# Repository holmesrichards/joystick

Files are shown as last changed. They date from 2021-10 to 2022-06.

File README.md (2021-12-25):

# Analog Output Joystick

This is a Kosmo format synth module that provides an interface for an analog joystick. The X and Y outputs provide control voltages that vary with the horizontal and vertical positions, respectively, of the joystick.

There are range control pots for X and Y. These adjust the width of the control voltage range. With the width fully clockwise the control voltage range is about 10 V end to end.

There also are offset control pots. These add a DC offset of between -5 V and 5 V to the output. So with the range pot at maximum and the offset pot centered the output voltage ranges from about -5 V to 5 V; with the offset pot fully clockwise the output voltage range is about 0 V to 10 V.

The X output voltage increases as you move the joystick from left to right, and Y increases from down to up. There also are two inverted output jacks; here the X output increases from right to left and the Y increases from up to down. Both outputs have the same range and same offset (with same sign), so for instance if the regular output is from 0 V to 10 V left to right, the inverted output will be 10 V to 0 V left to right.

## Current draw
16 mA +12 V, 16 mA -12 V

## Photos

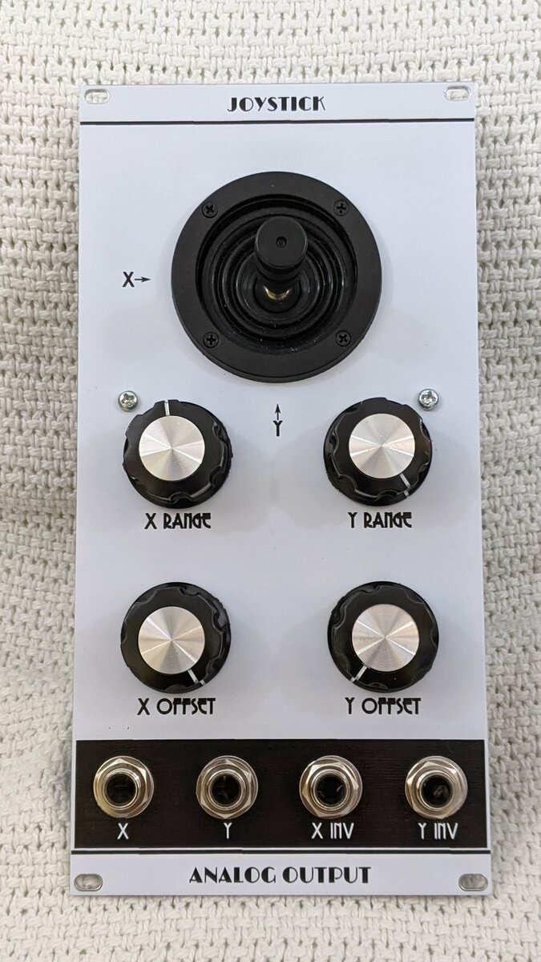
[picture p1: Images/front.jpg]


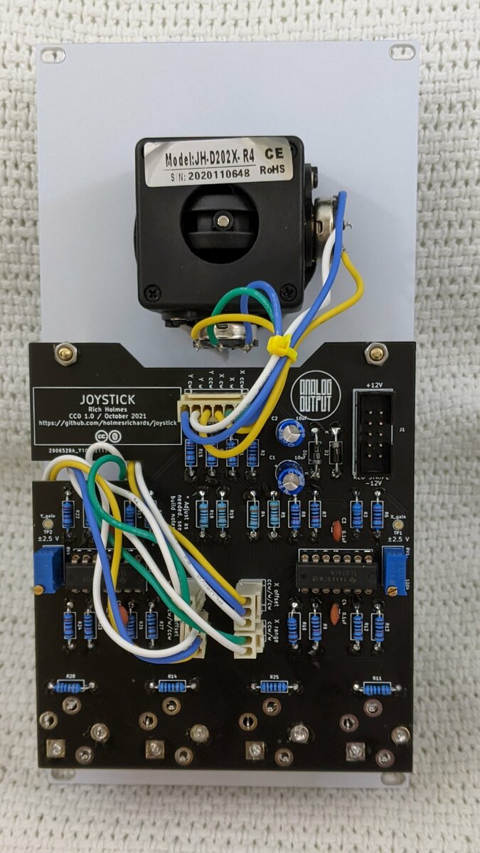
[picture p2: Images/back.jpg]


## Documentation

* [Schematic](Docs/joystick.pdf)
* PCB layout: [front](Docs/joystick_layout_front.pdf), [back](Docs/joystick_layout_back.pdf)
* [BOM](Docs/joystick_bom.md)
* [Build notes](Docs/build.md)
* [How it works](Docs/howitworks.md)

## GitHub repository

* [https://github.com/holmesrichards/joystick](https://github.com/holmesrichards/joystick)

## Submodules

This repo uses submodules aoKicad and Kosmo_panel, which provide needed libaries for KiCad. To clone:

```
git clone git@github.com:holmesrichards/joystick.git
git submodule init
git submodule update
```

Alternatively do

```
git clone --recurse-submodules git@github.com:holmesrichards/joystick.git
```

Or if you download the repository as a zip file, you must also click on the "aoKicad" and "Kosmo\_panel" links on the GitHub page (they'll have "@ something" after them) and download them as separate zip files which you can unzip into this repo's aoKicad and Kosmo\_panel directories.

If desired, copy the files from aoKicad and Kosmo\_panel to wherever you prefer (your KiCad user library directory, for instance, if you have one). Then in KiCad, add symbol libraries 

```
aoKicad/ao_symbols
Kosmo_panel/Kosmo
```
and footprint libraries 
```
aoKicad/ao_tht
Kosmo_panel/Kosmo_panel.
```

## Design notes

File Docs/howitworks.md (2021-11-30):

# How the Joystick module works

The X and Y parts of the circuit are identical. Each uses four op amps from a TL074 chip. Input to the first inverting op amp stage (U1A) is the voltage from a voltage divider consisting of a joystick pot and two fixed resistors (R1, R2). That voltage, in the range of about ±2.5 V, is scaled by a gain of up to -1 controlled by the range pot. The next stage (U1B) adds an offset that comes from a voltage divider consisting of the offset pot and two fixed resistors (R4, R5) in the range of about ±1.67 V. It sums the first stage output with a gain of -2 and the offset voltage gain of 3. So the output of U1B swings over about a 10 V range as the joystick is moved from one end to the other, and its central value is in the range from about -5 V to 5 V. This is the regular output.

The fourth stage (U1D) provides the inverted output. Just inverting the output of U2B would invert not only the joystick component but the offset, which isn't what we want. So to get the same sign offset, the third stage, non inverting (U1C), amplifies the original offset voltage by 3, and the fourth stage sums that with a gain of 2 and the U2B output with a gain of -1, which converts what would have been an inverted signal with inverted offset to an inverted signal with non inverted offset. This is the inverted output.

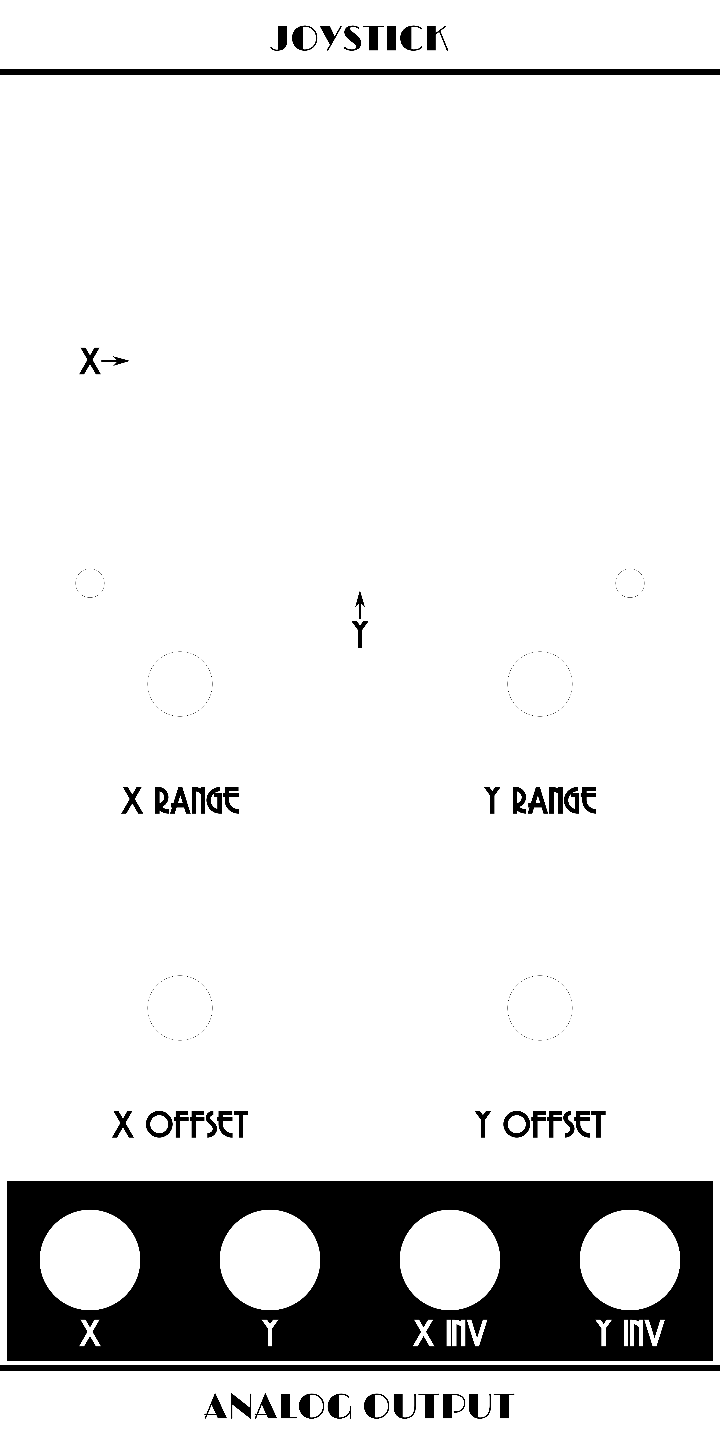
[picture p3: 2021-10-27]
Images/joystick_panel_art.png

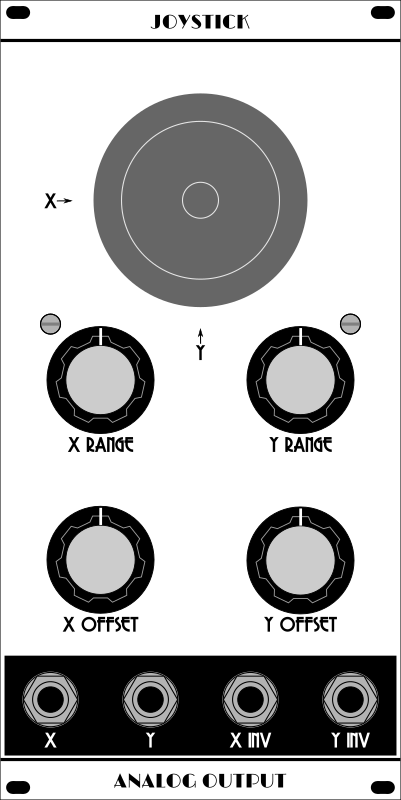
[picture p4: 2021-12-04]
Images/joystick_panel.png

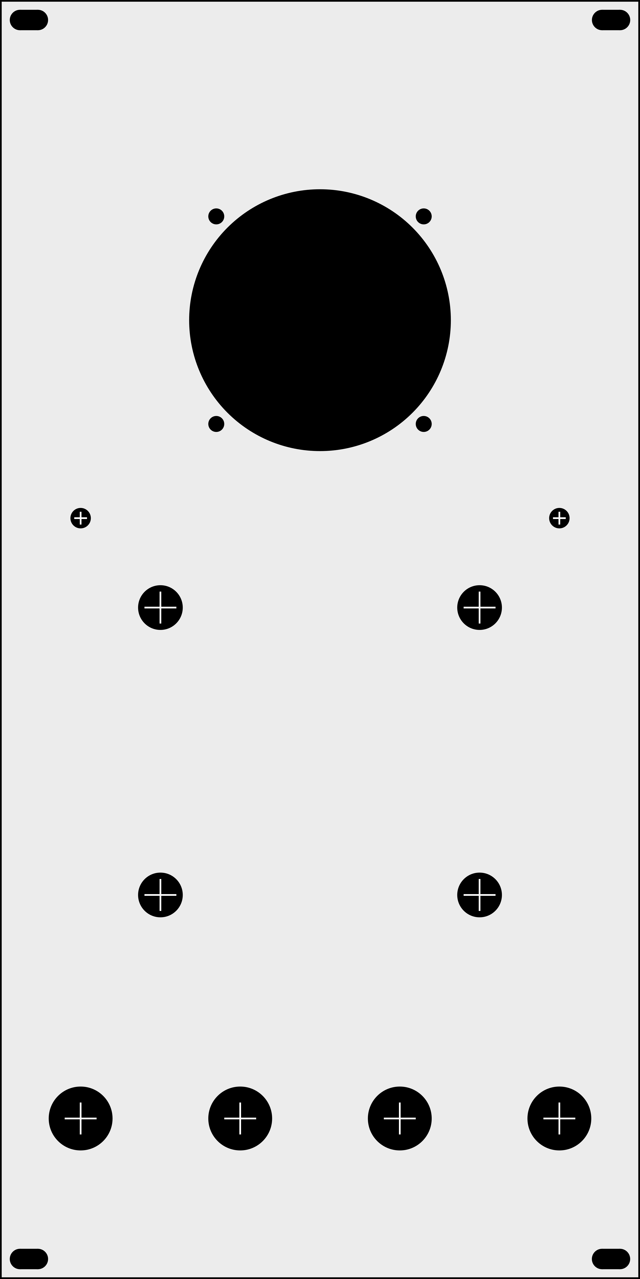
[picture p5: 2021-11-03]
Images/joystick_panel_holes.png

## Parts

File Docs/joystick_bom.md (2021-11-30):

# joystick.sch BOM

Tue 30 Nov 2021 05:13:07 PM EST

Generated from schematic by Eeschema 5.1.12-84ad8e8a86~92~ubuntu20.04.1

**Component Count:** 60

| Refs | Qty | Component | Description | Vendor | SKU |
| ----- | --- | ---- | --- | ---- | ---- |
| C1, C2 | 2 | 10uF | Electrolytic capacitor | Tayda | A-4349 |
| C3, C4, C5, C6 | 4 | 0.1uF | Ceramic capacitor | Tayda | A-553 |
| D1, D2 | 2 | 1N5817 | Schottky Barrier Rectifier Diode, DO-41 | Tayda | A-159 |
| J1 | 1 | Synth_power_2x5 | Shrouded header 2.54 mm 2x5 | Tayda | A-2939 |
| J2, J9 | 2 | 3_pin_Molex_connector | KK254 Molex connector | Tayda | A-827 |
| J3, J10 | 2 | 2_pin_Molex_connector | KK254 Molex connector | Tayda | A-826 |
| J4, J6, J11, J13 | 4 | AudioJack2 | Audio Jack, 2 Poles (Mono / TS) | Tayda | A-1121 |
| J5 | 1 | 6 pin Molex header | KK254 Molex connector | Tayda | A-808 |
| J7, J12 | 2 | 3_pin_Molex_header | KK254 Molex header | Tayda | A-805 |
| J8, J14 | 2 | 2_pin_Molex_header | KK254 Molex header | Tayda | A-804 |
| J15 | 1 | 6 pin Molex connector | KK254 Molex connector | Tayda | A-830 |
| R1, R2, R6, R8, R10, R15, R16, R20, R22, R24 | 10 | 20k | Resistor | Tayda |  |
| R3, R17 | 2 | 68k | Resistor | Tayda |  |
| R4, R5, R18, R19 | 4 | 300k* | Resistor | Tayda |  |
| R7, R9, R12, R13, R21, R23, R26, R27 | 8 | 10k | Resistor | Tayda |  |
| R11, R14, R25, R28 | 4 | 1k | Resistor | Tayda |  |
| RV1, RV4 | 2 | 100k | Trim-potentiometer | Tayda | A-587 |
| RV2, RV3, RV5, RV6 | 4 | B100k | Potentiometer | Tayda | A-1984 |
| RV7 | 1 | Joystick | Model JH-D202X-R4 10k | AliExpress |  |
| U1, U2 | 2 | TL074 | Quad operational amplifier, DIP-14 | Tayda | A-1138 |
| | 2 | 14 pin DIP socket || Tayda | A-003 |
| | 4 | Knob ||||
| | 2 | Spacers | M3 25 mm MF spacers | Tayda | A-1271 |
| | 2 | Nuts | M3 nuts | | |
| | 2 | Screws | M3 6mm screws | | |

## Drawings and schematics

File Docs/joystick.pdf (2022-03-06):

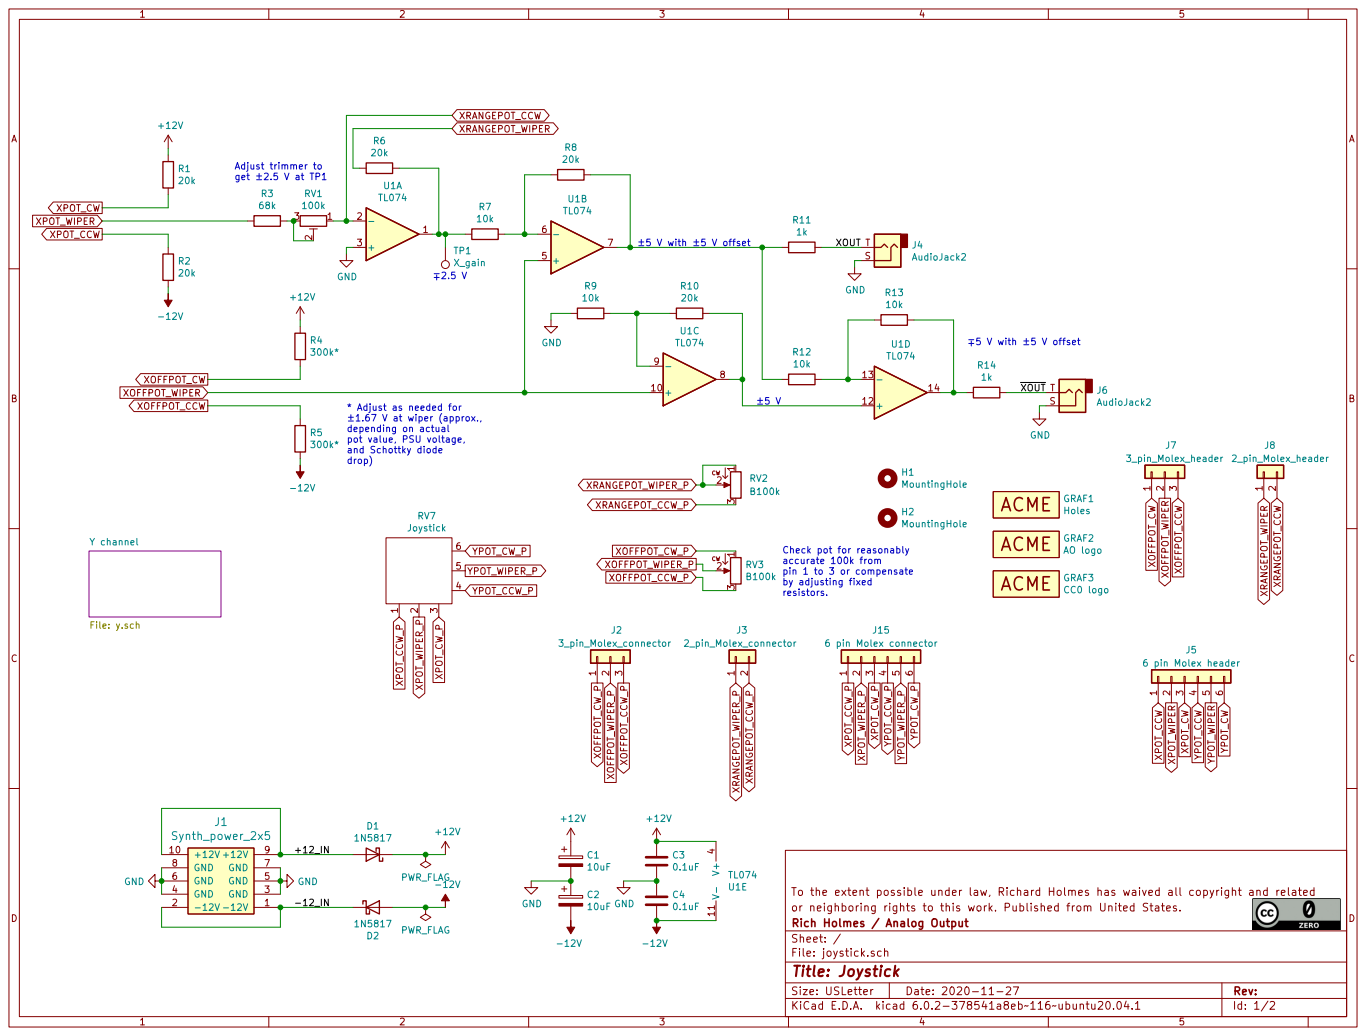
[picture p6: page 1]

6 pin Molex header H2MountingHole H1MountingHole GND

* Adjust as needed for
depending on actual
pot value, PSU voltage,
and Schottky diode
drop)

Check pot for reasonably accurate 100k from pin 1 to 3 or compensate

or neighboring rights to this work. Published from United States.
File: joystick.sch Sheet: / Rich Holmes / Analog Output

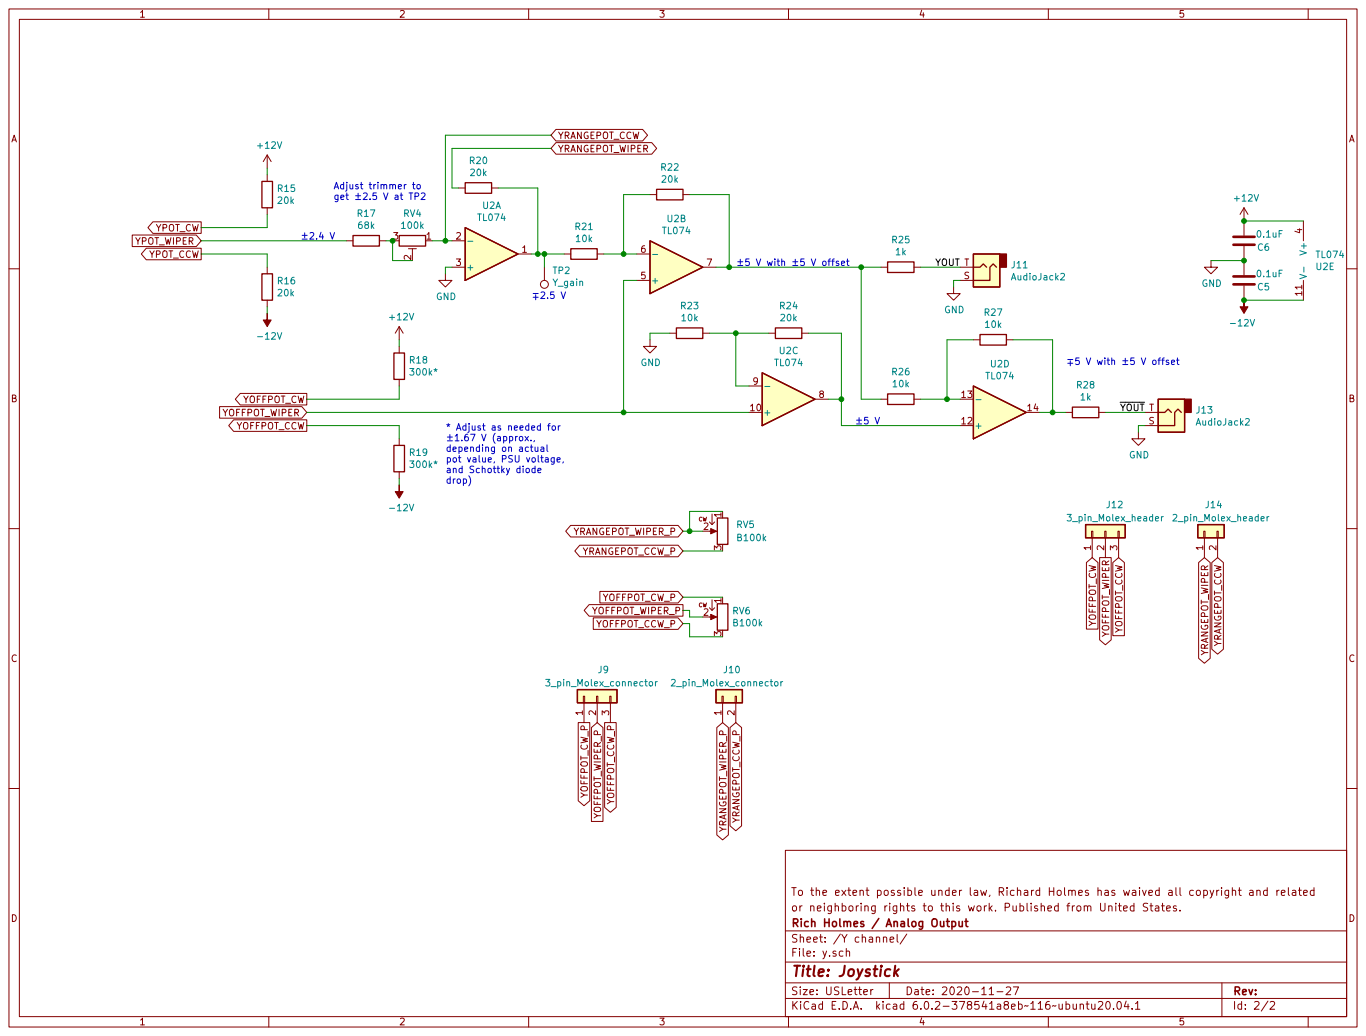
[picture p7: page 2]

* Adjust as needed for
depending on actual
pot value, PSU voltage,
and Schottky diode
drop)

To the extent possible under law, Richard Holmes has waived all copyright and related
or neighboring rights to this work. Published from United States.
File: y.sch Sheet: /Y channel/ Rich Holmes / Analog Output

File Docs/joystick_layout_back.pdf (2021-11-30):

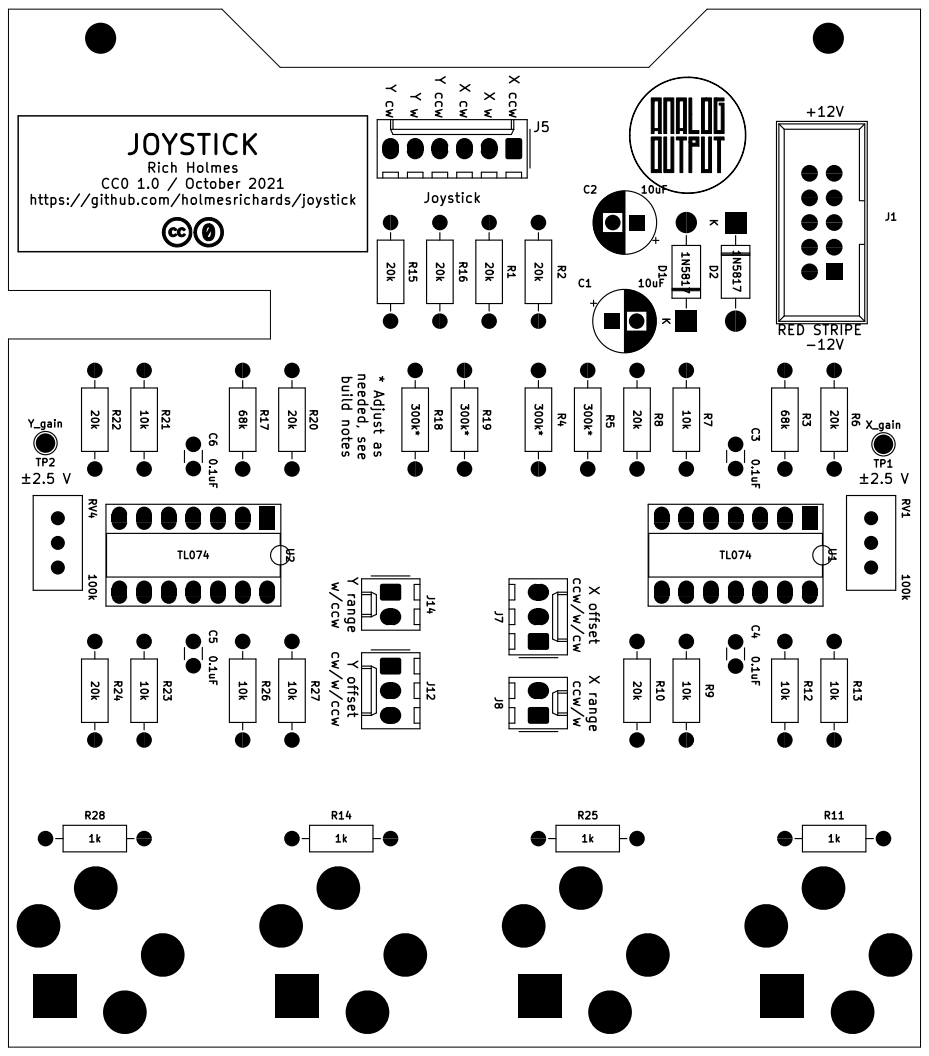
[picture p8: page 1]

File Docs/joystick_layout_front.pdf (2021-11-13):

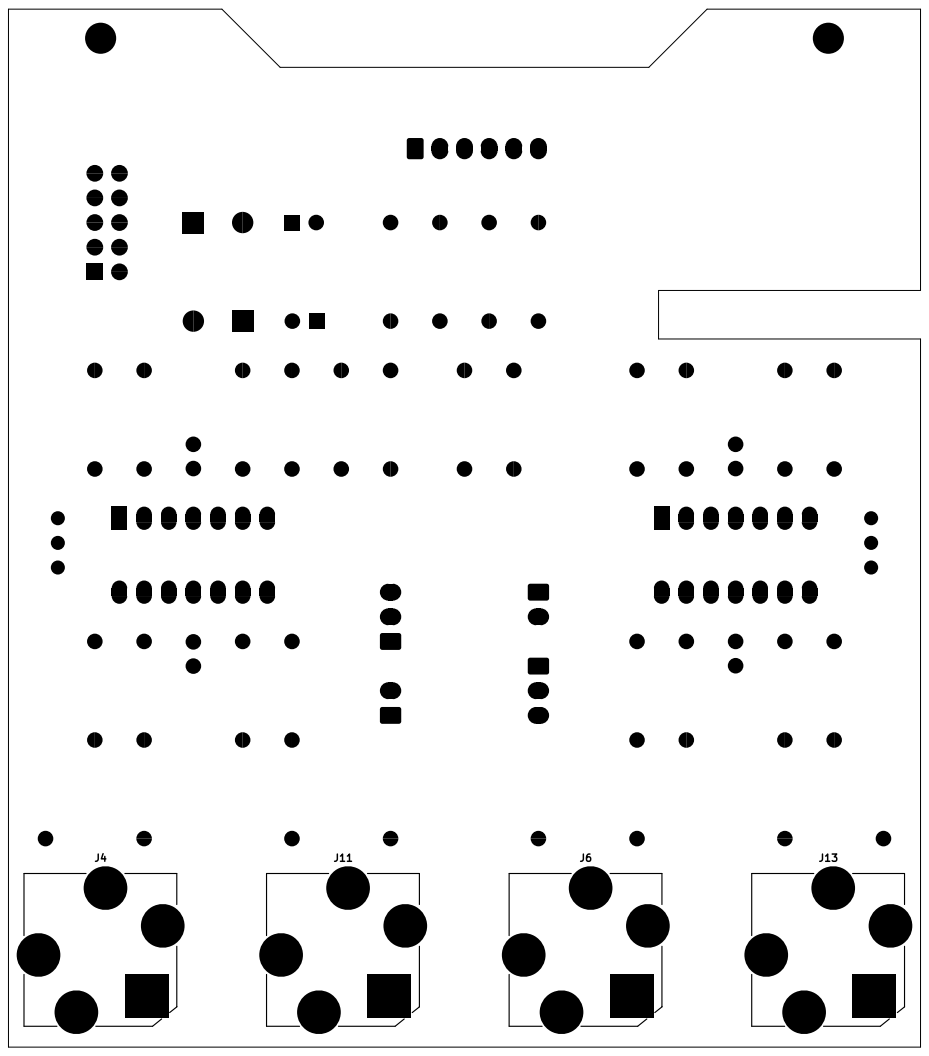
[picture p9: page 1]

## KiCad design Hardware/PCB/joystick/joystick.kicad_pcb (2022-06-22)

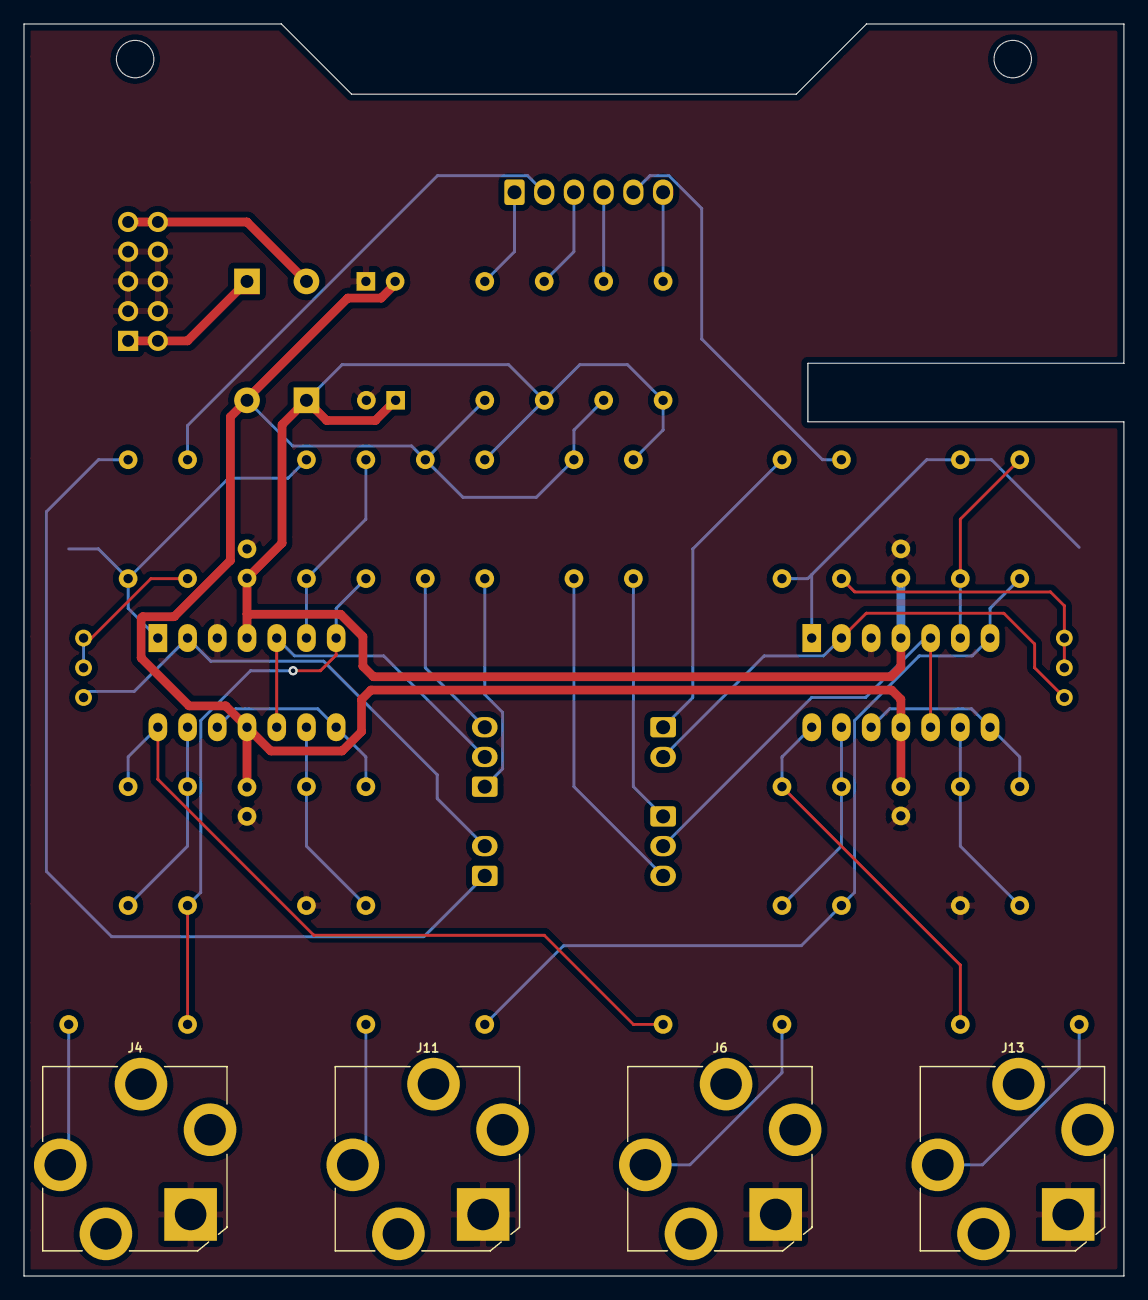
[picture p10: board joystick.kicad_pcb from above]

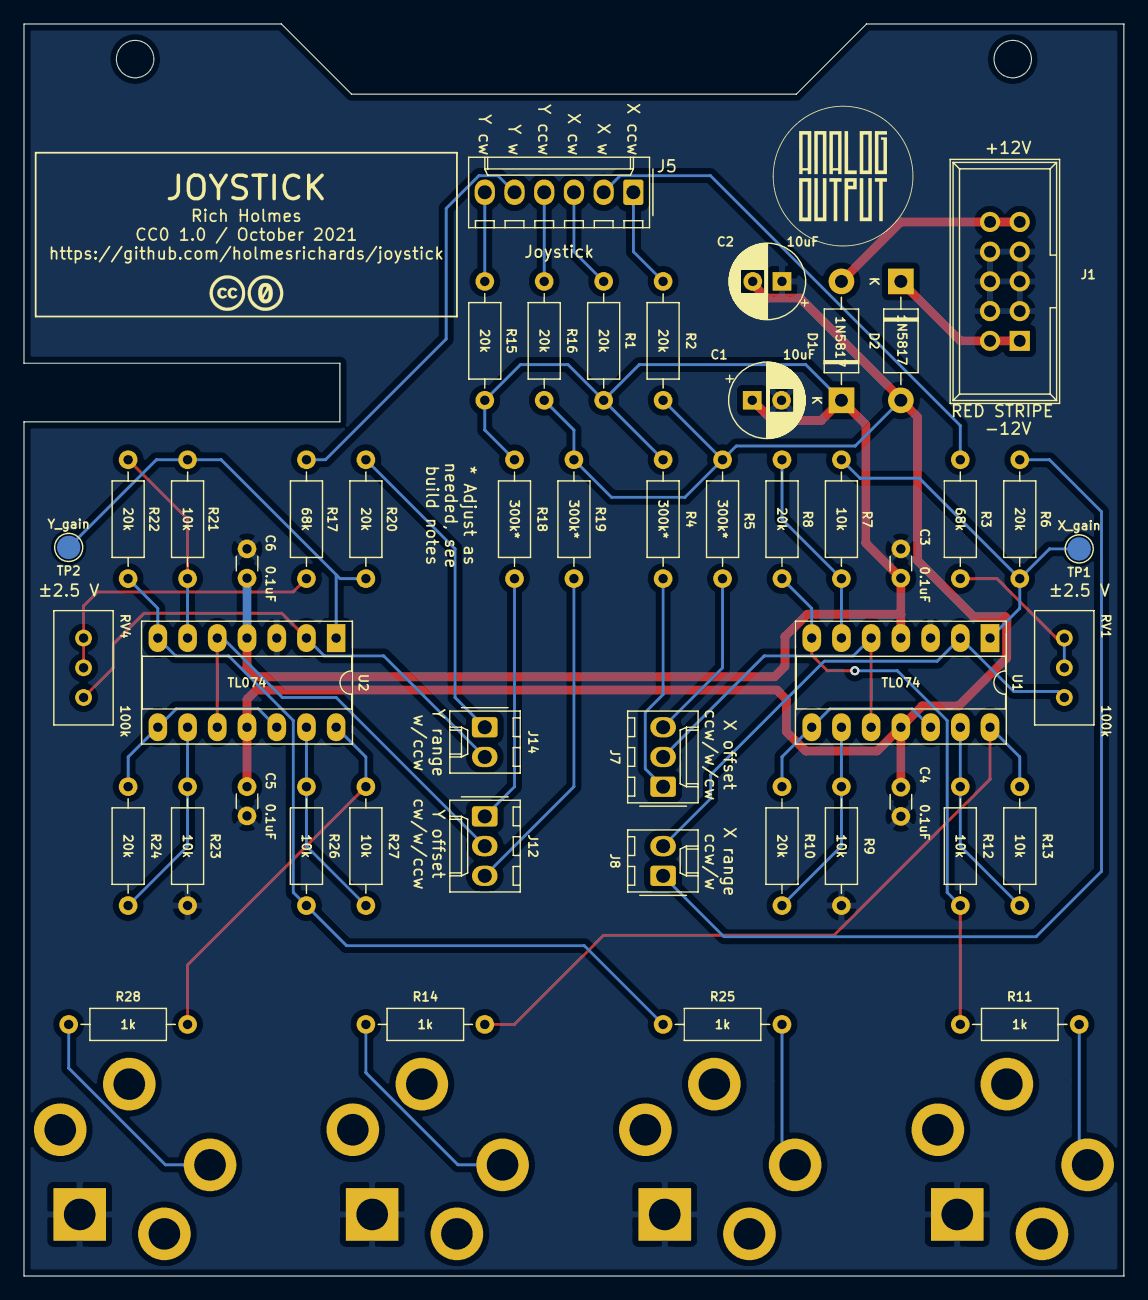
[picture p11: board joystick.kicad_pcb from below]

Board: 2 copper layers, 94.0 x 107.0 mm, 57 parts (50 on the bottom side), 41 nets.

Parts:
C1, C2: 10uF; CP_Radial_D6.3mm_P2.50mm
C3, C4, C5, C6: 0.1uF; C_Disc_D3.0mm_W1.6mm_P2.50mm
D1, D2: 1N5817; D_DO-41_SOD81_P10.16mm_Horizontal
GRAF1: Holes; joystick_panel_holes
GRAF2: AO logo; analogoutput_12mm
GRAF3: CC0 logo; CC0_logo
H1, H2: MountingHole; MountingHole_3.2mm_M3
J1: Synth_power_2x5; Power_Header
J4, J6, J11, J13: AudioJack2; Jack_6.35mm_PJ_629HAN
J5: 6 pin Molex header; Molex_KK-254_AE-6410-06A_1x06_P2.54mm_Vertical
J7, J12: 3_pin_Molex_header; Molex_KK-254_AE-6410-03A_1x03_P2.54mm_Vertical
J8, J14: 2_pin_Molex_header; Molex_KK-254_AE-6410-02A_1x02_P2.54mm_Vertical
R1, R2, R6, R8, R10, R15, R16, R20, R22, R24: 20k; R_Axial_DIN0207_L6.3mm_D2.5mm_P10.16mm_Horizontal
R3, R17: 68k; R_Axial_DIN0207_L6.3mm_D2.5mm_P10.16mm_Horizontal
R4, R5, R18, R19: 300k*; R_Axial_DIN0207_L6.3mm_D2.5mm_P10.16mm_Horizontal
R7, R9, R12, R13, R21, R23, R26, R27: 10k; R_Axial_DIN0207_L6.3mm_D2.5mm_P10.16mm_Horizontal
R11, R14, R25, R28: 1k; R_Axial_DIN0207_L6.3mm_D2.5mm_P10.16mm_Horizontal
RV1, RV4: 100k; Potentiometer_Bourns_3296W_Vertical_standard
TP1: X_gain; TestPoint_Pad_D2.0mm
TP2: Y_gain; TestPoint_Pad_D2.0mm
U1, U2: TL074; DIP-14_W7.62mm_Socket_LongPads

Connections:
+12V: C1.1, C3.1, C6.2, D1.1, R1.1, R4.1, R15.1, R18.1, U1.4, U2.4
-12V: C2.2, C4.2, C5.1, D2.2, R2.2, R5.2, R16.2, R19.2, U1.11, U2.11
/+12_IN: D1.2, J1.9, J1.10
/-12_IN: D2.1, J1.1, J1.2
/XOUT: J4.T, R11.1
/Y channel/YOUT: J11.T, R25.1
/Y channel/~YOUT: J13.T, R28.1
/~XOUT: J6.T, R14.1
GND: C1.2, C2.1, C3.2, C4.1, C5.2, C6.1, J1.3, J1.4, J1.5, J1.6, J1.7, J1.8, J4.S, J6.S, J11.S, J13.S, R9.2, R23.2, U1.3, U2.3
unnamed: R3.1, RV1.2, RV1.3
unnamed: R6.1, R7.2, TP1.1, U1.1
unnamed: R7.1, R8.2, U1.6
unnamed: R10.1, U1.8, U1.12
unnamed: R9.1, R10.2, U1.9
unnamed: R8.1, R11.2, R12.2, U1.7
unnamed: R12.1, R13.2, U1.13
unnamed: R13.1, R14.2, U1.14
unnamed: R17.1, RV4.2, RV4.3
unnamed: R20.1, R21.2, TP2.1, U2.1
unnamed: R21.1, R22.2, U2.6
unnamed: R22.1, R25.2, R26.2, U2.7
unnamed: R23.1, R24.2, U2.9
unnamed: R24.1, U2.8, U2.12
unnamed: R26.1, R27.2, U2.13
unnamed: R27.1, R28.2, U2.14
XOFFPOT_CCW: J7.3, R5.1
XOFFPOT_CW: J7.1, R4.2
XOFFPOT_WIPER: J7.2, U1.5, U1.10
XPOT_CCW: J5.1, R2.1
XPOT_CW: J5.3, R1.2
XPOT_WIPER: J5.2, R3.2
XRANGEPOT_CCW: J8.2, RV1.1, U1.2
XRANGEPOT_WIPER: J8.1, R6.2
YOFFPOT_CCW: J12.3, R19.1
YOFFPOT_CW: J12.1, R18.2
YOFFPOT_WIPER: J12.2, U2.5, U2.10
YPOT_CCW: J5.4, R16.1
YPOT_CW: J5.6, R15.2
YPOT_WIPER: J5.5, R17.2
YRANGEPOT_CCW: J14.2, RV4.1, U2.2
YRANGEPOT_WIPER: J14.1, R20.2

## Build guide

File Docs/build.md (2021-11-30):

# Joystick build notes

This is mostly a straightforward build, but read below for some important information.

# Joystick

The joystick is a model JH-D202X-R4, available on sites such as AliExpress, Amazon Marketplace, and eBay. There are various versions of this joystick; I designed for the one with 10k potentiometers. (Using different pots just requires adjusting resistance values, though.)

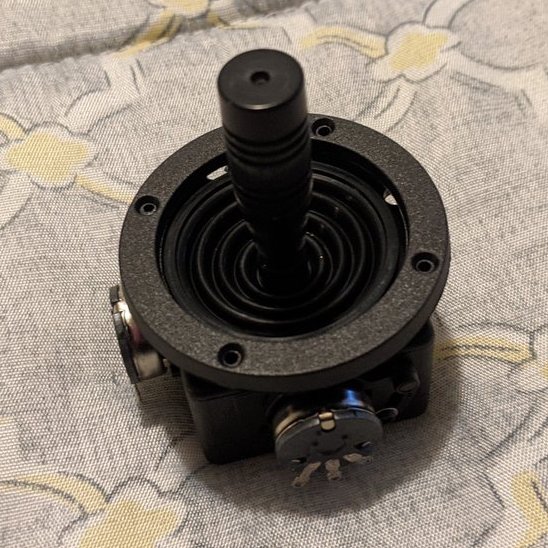
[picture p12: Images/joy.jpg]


As supplied, the joystick has springs that pull the stick back to center when released. If you don't want that behavior, you can remove the cover of the joystick to reveal the springs:

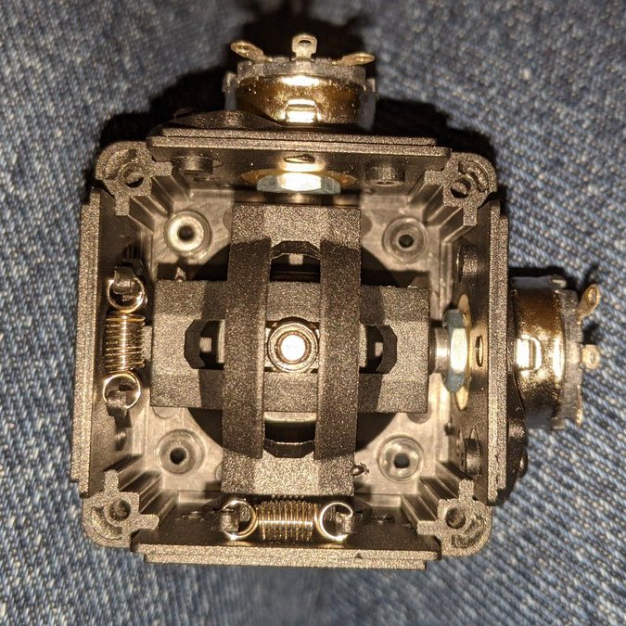
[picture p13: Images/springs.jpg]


You can remove the springs without breaking anything. Save them somewhere you can find them in case you change your mind!

Without the springs the joystick still will return toward the center if released at extreme positions due to the rubber boot. You can just cut the boot off and leave it out but I found I could use a small pair of sharp scissors to widen the central hole in the boot, and then the joystick will stay put when released. Enough of the boot will be left to look good and prevent at least some amount of dust from getting in.

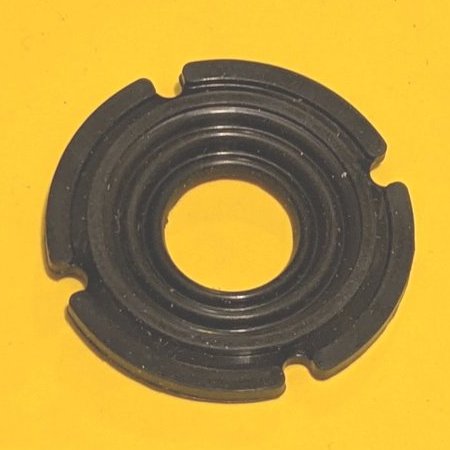
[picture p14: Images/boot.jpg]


## Pot and resistor values and calibration

Pot tolerances being what they are, or rather aren't (20% for Alphas!), there are trimmers provided to tune the joystick range. Measure voltage at each test point and adjust the corresponding trimmer to get about ±2.5 V at the extremes of the joystick motion. I found the limits were asymmetric, I'm guessing due to different power rail voltages due to different loads on the Schottky diodes, so I aimed for 2.5 V on whichever had the smaller size. The output range will be about 4x this voltage, so 10 V end to end.

There are no trimmers to adjust the offset ranges, because I care less about that and because each is affected by only one pot versus the two that affect the joystick range. They should be approximately ±1.67 V at the pot wiper (depending on the actual pot value, PSU voltage, and Schottky diode drop), and a little large is better than a little small. You can select pots that measure as close as possible to 100k, or compensate for a too large or too small pot value by adjusting the 300k resistor values. I suggest

|With actual pot resistance|Use fixed resistors|
|----|---|
| 80k–90k | 240k |
| 90k–100k | 270k |
| 100k–110k | 300k |
| 110k–120k | 330k |

though none of this is critical. The offset range on the outputs should come out to about -5 V to 5 V.

## Wiring connections

The footprint for the 6-position Molex connector is labeled with things like "X ccw" and "Y cw", but don't take that too literally. The joystick can be mounted in any of four orientations and the wiring will differ for each. So move the joystick left and measure the resistances of the horizontal pot end terminals to the wiper to see which end the wiper shorts to; that will be your "X ccw" terminal regardless of whether you think it's really counterclockwise or not. Likewise, move the joystick down and identify the vertical pot terminal that shorts to the wiper, and that's your "Y ccw" terminal. The other ends connect to the "cw" positions and the wipers to the "w" positions.

Here's what I did:

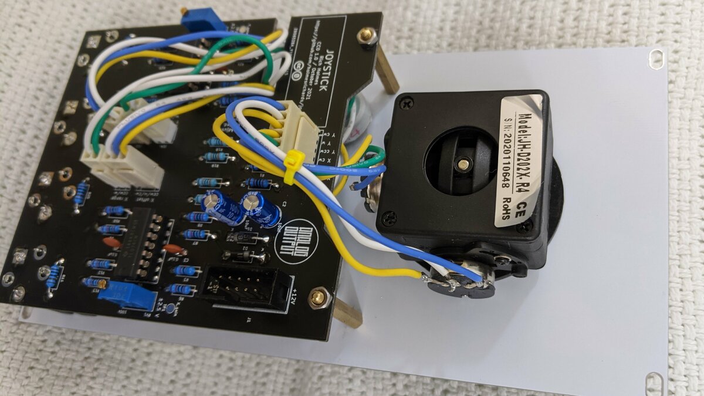
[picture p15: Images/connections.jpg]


The other pots are more straightforward, with the counterclockwise (as viewed from front) terminal connecting to "ccw", et cetera. On the range pots it actually doesn't matter which way around they are connected to the PCB, but you do want to make sure to connect the wiper to the cw end, leaving that and the ccw end to be wired to the connector.

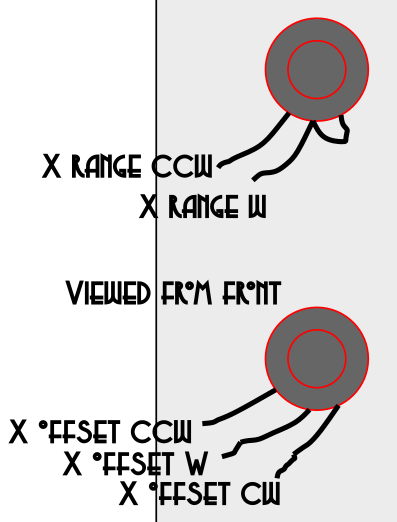
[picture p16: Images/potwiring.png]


## Errata

On the first run of PCBs, R2 is shown on the silkscreen as 15k. It should be 20k. This has been fixed in the KiCad files and Gerbers.

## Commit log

2021-10-01 Initial version
    [joystick.kicad_pcb, joystick.sch, pots.sch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]
2021-10-02 Panel design and Gerbers
    [joystick_panel.kicad_pcb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]
2021-10-02 Panel design
    [joystick_panel.sch]
2021-10-27 Belated .gitignore; switch to panel mounted pots implying board and panel changes
    [joystick.kicad_pcb, joystick.sch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]
2021-10-27 Page setup
    [joystick.sch, y.sch]
2021-11-03 Add gain trimmers and test points
    [joystick.kicad_pcb, joystick.sch, joystick_panel.kicad_pcb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]
2021-11-03 Move trimmers to inputs
    [joystick_panel.kicad_pcb]
2021-11-03 More tweaks, build.md
    [joystick.kicad_pcb, joystick.sch, y.sch]
2021-11-03 Change voltage ranges
    [joystick.kicad_pcb, joystick.sch, y.sch]
2021-11-03 Move trimmers and TPs to back
    [joystick.kicad_pcb, joystick.sch, joystick_panel.kicad_pcb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]
2021-11-13 Update docs, generate Gerbers
    [joystick-B_Cu.gbr, joystick-B_Mask.gbr, joystick-B_SilkS.gbr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]
2021-11-29 Correct resistor value
    [joystick.sch]
2021-11-30 Fix wrong R value; update documentation; images
    [joystick.kicad_pcb, joystick.sch]
2021-12-01 Corrected Gerbers (silkscreen)
    [joystick-B_Cu.gbr, joystick-B_Mask.gbr, joystick-B_SilkS.gbr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]
2021-12-24 Current draw
2022-03-06 copy and paste typo
    [y.sch]
2022-06-22 KiCad 6
    [joystick.kicad_pcb, joystick.kicad_sch, joystick.sch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]
